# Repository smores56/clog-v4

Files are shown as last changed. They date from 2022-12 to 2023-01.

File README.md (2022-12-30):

The Clog V4
===========

The Clog V4 is a 34-key split keyboard. It has the following features:

- Choc V1 switches
- Wired or wireless with Seeeduino Xiao controllers
- Pinky clusters (top pinky keys on the sides)
- Splay (4° between middle and ring and between ring and pinky)
- Hotswap with a switch plate for stability
- SplitKB puck support for tenting

One Half of the Clog V4

## How to Order

The gerber ZIPs ((PCB)[./gerber/clog-v4.zip] and (plate)[./gerber/clog-v4-plate.zip])
have everything you'll need to get this printed. You can order from [JLC](https://jlcpcb.com)
by just uploading the ZIP archives and keeping the default options. I'd suggest removing
the order number, otherwise they'll put one on the boards somewhere randomly.

## Building

### Parts Needed

Part Name                  | Quantity        | Notes                                    | Link
--------------------------:|:---------------:|:----------------------------------------:|:----
PCB                        | 2 (halves)      |                                          | Look up
Switch Plate               | 2 (halves)      |                                          | Look up
Choc V1 Switches           | 34              |                                          | <https://mkultra.click/choc-switches>
Choc Keycaps               | 34              |                                          | <https://mkultra.click/mbk-factory-colors>
SMD Diodes                 | 34              |                                          | <https://www.aliexpress.com/item/3256802562651339.html>
Kailh Choc Hotswap Sockets | 34              |                                          | <https://mkultra.click/kailh-hotswap-sockets>
Power Switches             | 2               | optional                                 | <https://www.digikey.com/en/products/detail/nidec-copal-electronics/CUS-12TB/1124222>
Reset Switches             | 2               | optional                                 | <https://www.digikey.com/en/products/detail/e-switch/TL1014BF160QG/3910805>
Xiao (BLE)                 | 2               |                                          | <https://www.seeedstudio.com/Seeed-XIAO-BLE-nRF52840-p-5201.html>
Small LiPo Batteries       | 2               |                                          | <https://www.aliexpress.com/item/2251832610867849.html>
Inch of Copper Wire        | 1               | Use thin and sheathed                    | Any hardware store
MCU Sockets                | 1 strip to chop | Optional, chop into sections of 7 pins   | <https://www.digikey.com/en/products/detail/mill-max-manufacturing-corp/316-43-164-41-006000/1212147>
MCU Socket Pins            | 28              | Optional, buy extras, these are slippery | <https://www.digikey.com/en/products/detail/mill-max-manufacturing-corp/3320-0-00-15-00-00-03-0/4147392>

### Tips

I'd solder the parts in this order:

- Diodes
- Hotswap sockets
- Power switches
- MCU sockets/Headers that came with the Xiao's
- MCU pins if you're [socketing](https://docs.splitkb.com/hc/en-us/articles/360011263059-How-do-I-socket-a-microcontroller-)
- Batteries (To the +ve pad under the controller and to the -ve hole on the board)
- The "bodge" wire from the "Reset" hole to the reset pad under the controller

## Pictures

The Clog V4

Tented with Pucks and Manfrotto Tripods

The Clog Logo

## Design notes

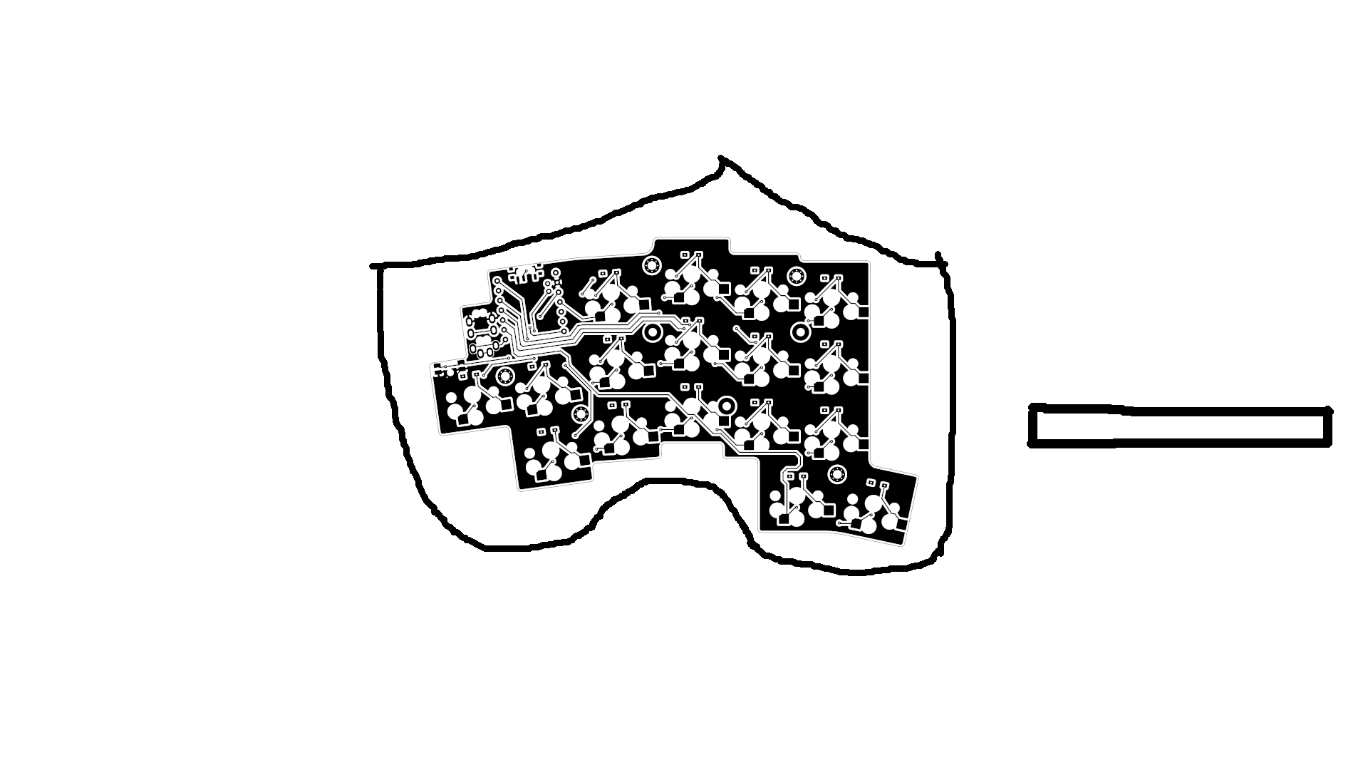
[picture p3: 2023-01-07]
art/shoe-outline-1.png

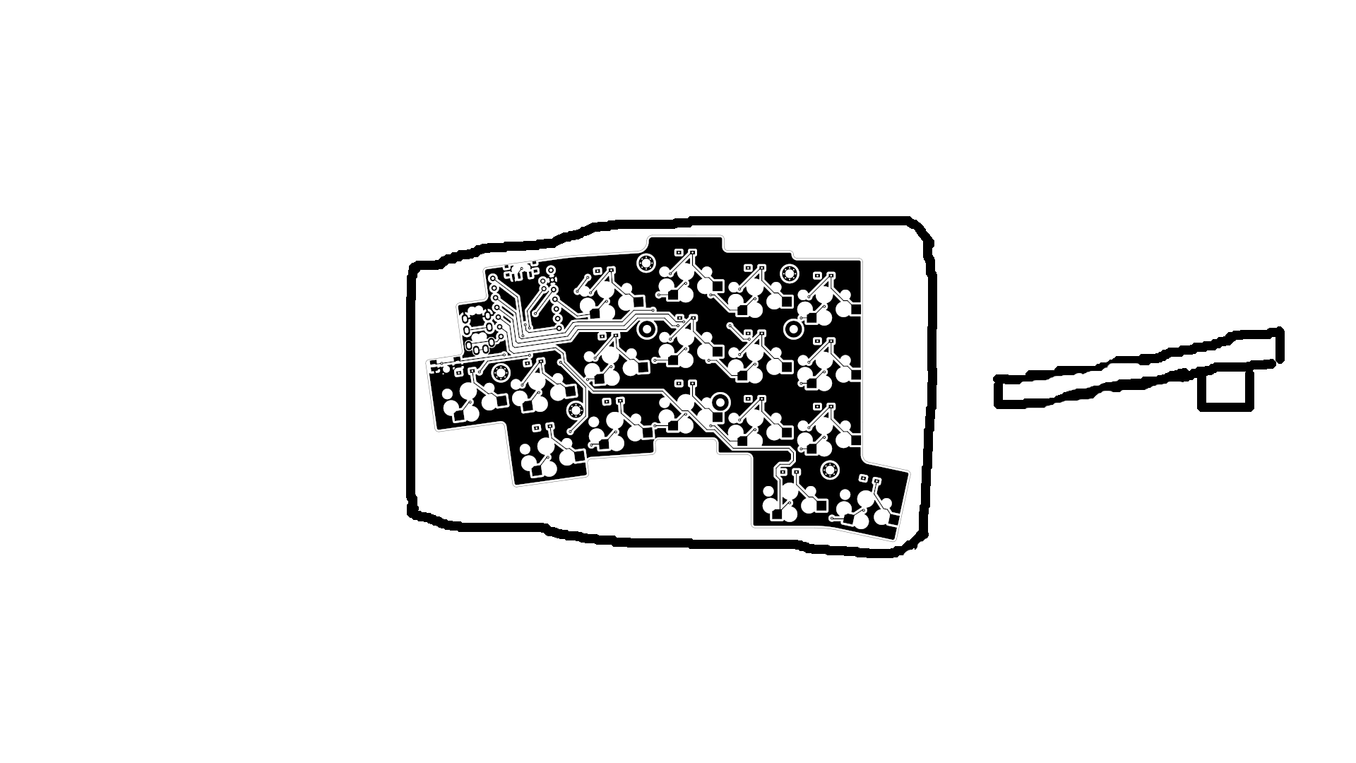
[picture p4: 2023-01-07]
art/shoe-outline-2.png

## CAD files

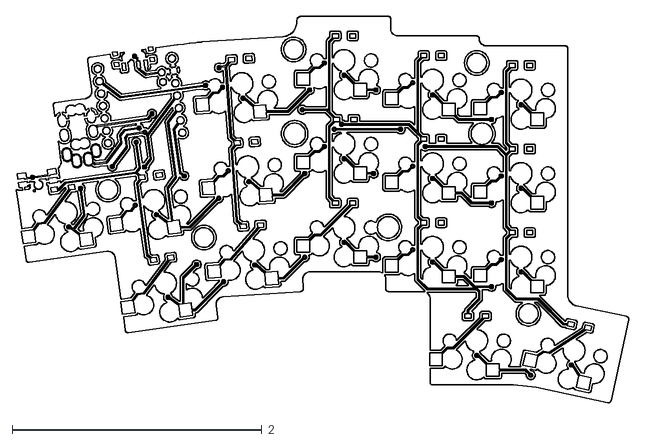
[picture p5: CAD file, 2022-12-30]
case/full-pcb.dxf
4.90 x 3.10

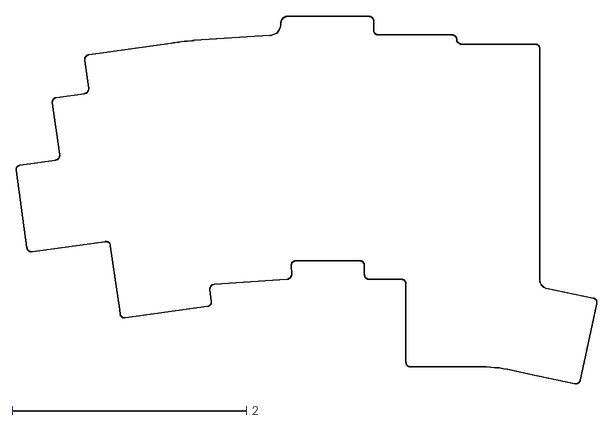
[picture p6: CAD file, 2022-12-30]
case/empty-pcb.dxf
4.96 x 3.14

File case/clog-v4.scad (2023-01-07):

hole_locations = [
    [45.9, -53],
    [26.4, -43.3],
    [64.2, -14.8],
    [101.4, -17.5],
    [111.9, -68.5],
];

pcb_thickness = 1.6;
component_thickness = 2;
case_thickness = 1.5;

plate_thickness = 1.2;
pcb_plate_gap = 1;

total_plate_thickness = plate_thickness + pcb_plate_gap;

total_thickness = pcb_thickness +
    component_thickness + case_thickness +
    total_plate_thickness;

pcb_case_margin = 0.5;
pcb_ridge_margin = 1;

case_wall_thickness = 4;

heat_insert_radius = 1.5;
strut_radius = 3;

// rendering level
$fn = 15;

right_side = true;

module pcb() {
    translate([-75, 50, 0])
    scale([25.4, 25.4, 1])
    import("empty-pcb.dxf");
}

module pcb_ghost() {
    %
    translate([0, 0, case_thickness + component_thickness])
    linear_extrude(pcb_thickness)
    pcb();
}

module pcb_cutout() {
    translate([0, 0, case_thickness + component_thickness])
    linear_extrude(pcb_thickness + total_plate_thickness + 1)
    offset(pcb_case_margin)
    pcb();
}

module component_cutout() {
    translate([0, 0, case_thickness])
    linear_extrude(component_thickness + pcb_thickness + 0.1)
    offset(-pcb_ridge_margin)
    pcb();
}

module case_body() {
    minkowski() {
        linear_extrude(total_thickness)
        offset(case_wall_thickness)
        pcb();
        sphere(0.5);
    }
}

module heat_insert_holes() {
    for (location = hole_locations) {
        translate([location[0], location[1], case_thickness + component_thickness - 3])
        linear_extrude(10)
        circle(heat_insert_radius);
    }
}

module heat_insert_struts() {
    for (location = hole_locations) {
        translate([location[0], location[1], case_thickness - 0.1])
        linear_extrude(component_thickness)
        circle(strut_radius);
    }
}

module wire_port_cutout() {
    translate([24.135, -28, case_thickness + component_thickness + total_thickness / 2+ pcb_thickness])
    rotate([0, 0, 8])
    cube([38.75, 35, total_thickness], center=true);
}

module power_switch_cutout() {
    z_rotation_base = 8;
    z_rotation_delta = 15;

    intersection() {
        translate([27.7, -18.5, 1])
        rotate([0, 0, z_rotation_base + z_rotation_delta])
        cube([12, 10, 6]);

        translate([23.7, -16, 1])
        rotate([0, 0, z_rotation_base - z_rotation_delta])
        cube([12, 10, 6]);

        translate([24.7, -17, 2])
        rotate([-10, 0, z_rotation_base])
        cube([15, 10, 6]);
    }
}

module reset_switch_cutout() {
    intersection() {
        translate([6.4, -42.3, 3])
        rotate([-15, 0, 8])
        cube([10, 15, 6]);
        
        translate([6.4, -41.03, 0])
        rotate([0, 0, 8])
        cube([10, 15, 9]);

        translate([6.4, -46, 1])
        rotate([0, 0, 28])
        cube([10, 21, 6]);
    }
}

module full_case() {
    difference() {
        union() {
            difference() {
                case_body();
                pcb_cutout();
                component_cutout();
                wire_port_cutout();
                power_switch_cutout();
                reset_switch_cutout();
            };
            heat_insert_struts();
        };
        heat_insert_holes();
        pcb_ghost();
    };
}

if (right_side) {
    translate([110, 0, 0])
    mirror([1, 0, 0])
    full_case();
} else {
    full_case();
};

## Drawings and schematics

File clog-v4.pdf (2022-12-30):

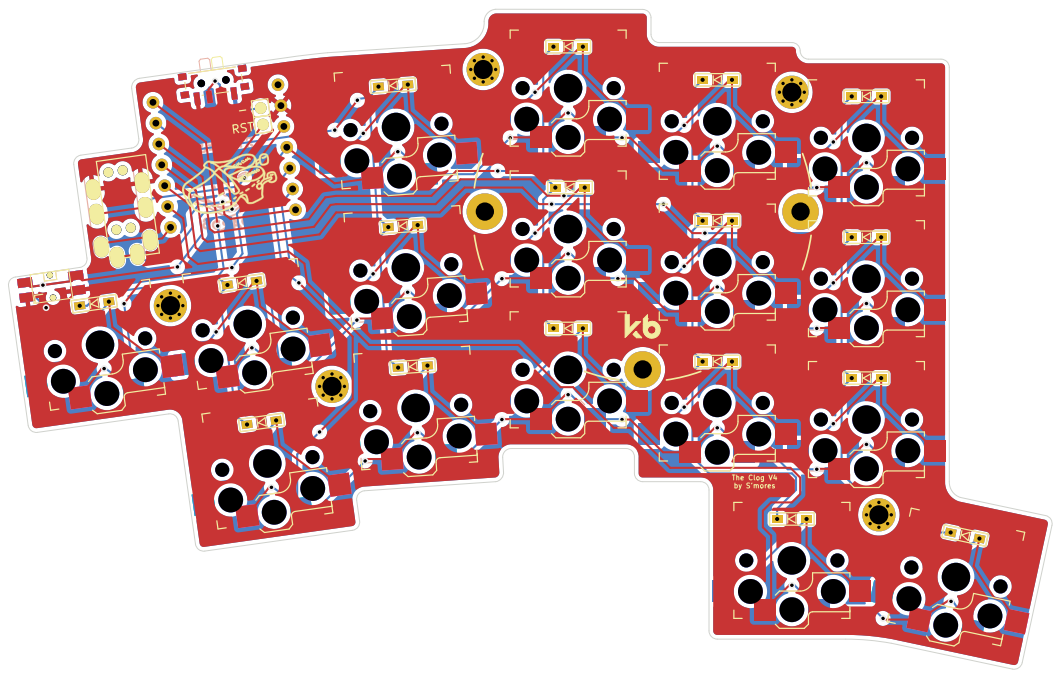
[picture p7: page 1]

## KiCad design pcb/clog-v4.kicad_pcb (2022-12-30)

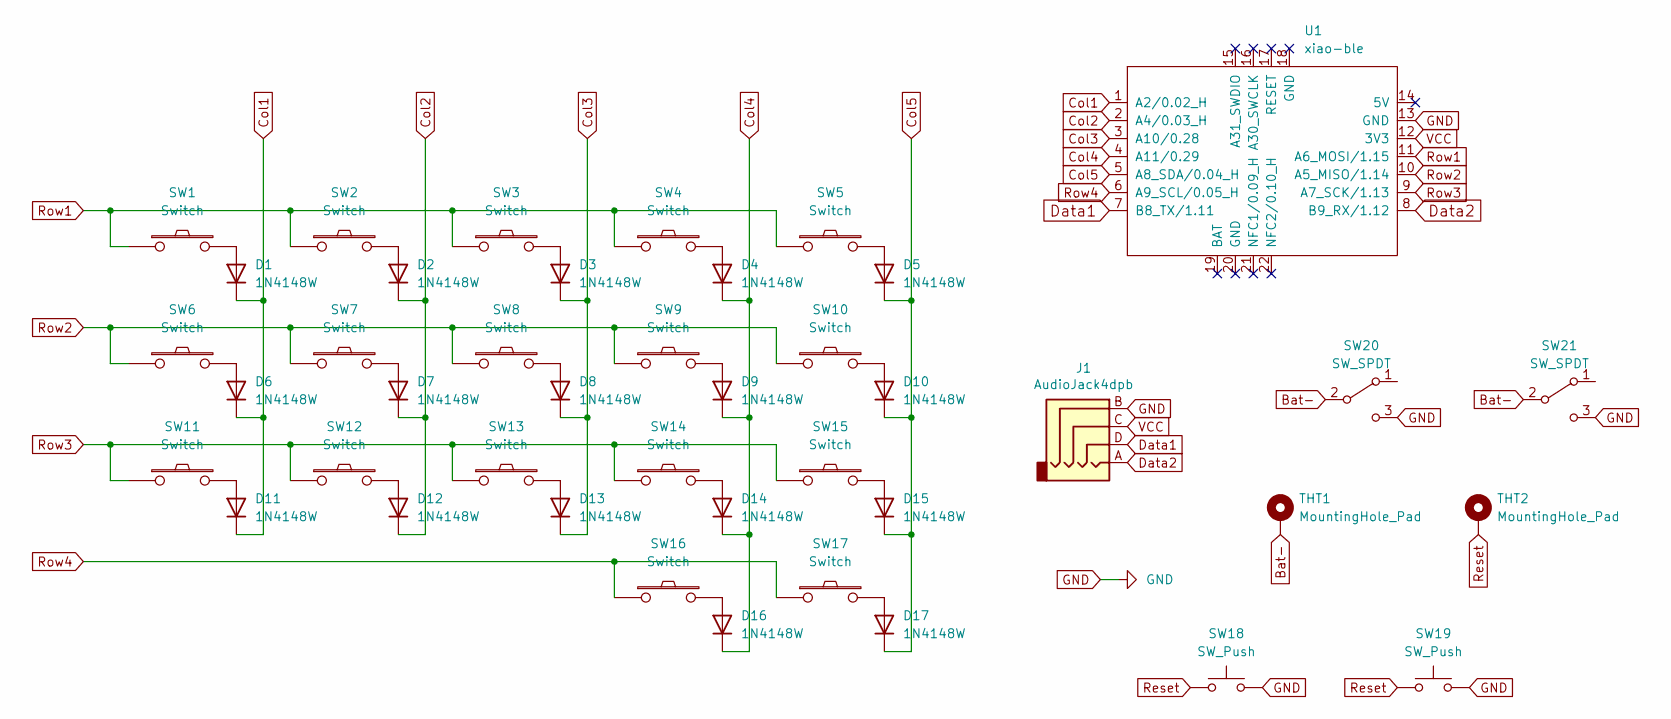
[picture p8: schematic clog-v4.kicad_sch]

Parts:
D1, D2, D3, D4, D5, D6, D7, D8, D9, D10, D11, D12, D13, D14, D15, D16, D17: 1N4148W; smd-diode
J1: AudioJack4dpb; trrs
SW1, SW2, SW3, SW4, SW5, SW6, SW7, SW8, SW9, SW10, SW11, SW12, SW13, SW14, SW15, SW16, SW17: Switch; choc-switch-socket-only
SW18, SW19: SW_Push; reset-switch-angled-4pin
SW20, SW21: SW_SPDT; power-switch
THT1, THT2: MountingHole_Pad; single-pin
U1: xiao-ble

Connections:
Bat-: SW20.2 (B), SW21.2 (B), THT1.1
Col1: D1.1 (K), D6.1 (K), D11.1 (K), U1.1 (A2/0.02_H)
Col2: D2.1 (K), D7.1 (K), D12.1 (K), U1.2 (A4/0.03_H)
Col3: D3.1 (K), D8.1 (K), D13.1 (K), U1.3 (A10/0.28)
Col4: D4.1 (K), D9.1 (K), D14.1 (K), D16.1 (K), U1.4 (A11/0.29)
Col5: D5.1 (K), D10.1 (K), D15.1 (K), D17.1 (K), U1.5 (A8_SDA/0.04_H)
Data1: J1.D, U1.7 (B8_TX/1.11)
Data2: J1.A, U1.8 (B9_RX/1.12)
GND: J1.B, SW18.2, SW19.2, SW20.3 (C), SW21.3 (C), U1.13 (GND)
unnamed: D1.2 (A), SW1.2
unnamed: D2.2 (A), SW2.2
unnamed: D3.2 (A), SW3.2
unnamed: D4.2 (A), SW4.2
unnamed: D5.2 (A), SW5.2
unnamed: D6.2 (A), SW6.2
unnamed: D7.2 (A), SW7.2
unnamed: D8.2 (A), SW8.2
unnamed: D9.2 (A), SW9.2
unnamed: D10.2 (A), SW10.2
unnamed: D11.2 (A), SW11.2
unnamed: D12.2 (A), SW12.2
unnamed: D13.2 (A), SW13.2
unnamed: D14.2 (A), SW14.2
unnamed: D15.2 (A), SW15.2
unnamed: D16.2 (A), SW16.2
unnamed: D17.2 (A), SW17.2
Reset: SW18.1, SW19.1, THT2.1
Row1: SW1.1, SW2.1, SW3.1, SW4.1, SW5.1, U1.11 (A6_MOSI/1.15)
Row2: SW6.1, SW7.1, SW8.1, SW9.1, SW10.1, U1.10 (A5_MISO/1.14)
Row3: SW11.1, SW12.1, SW13.1, SW14.1, SW15.1, U1.9 (A7_SCK/1.13)
Row4: SW16.1, SW17.1, U1.6 (A9_SCL/0.05_H)
VCC: J1.C, U1.12 (3V3)

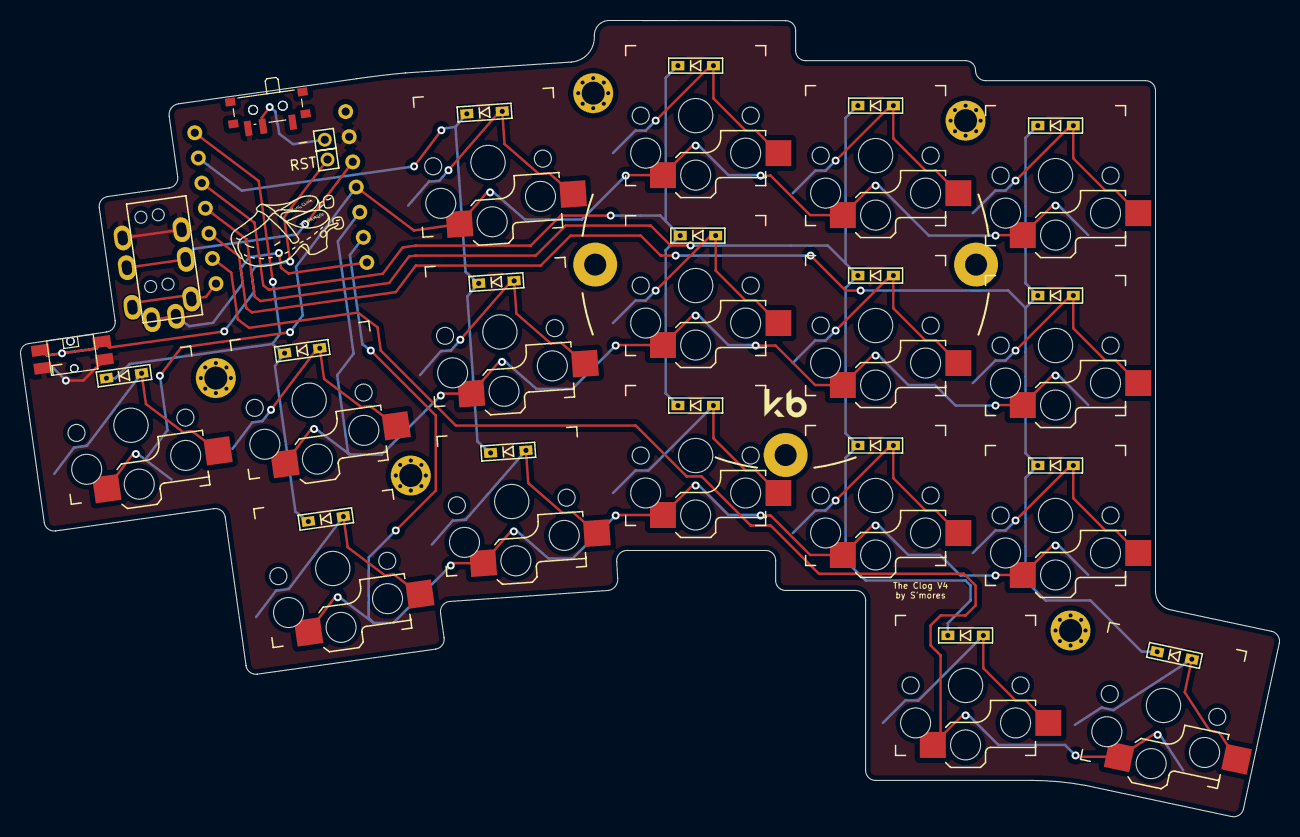
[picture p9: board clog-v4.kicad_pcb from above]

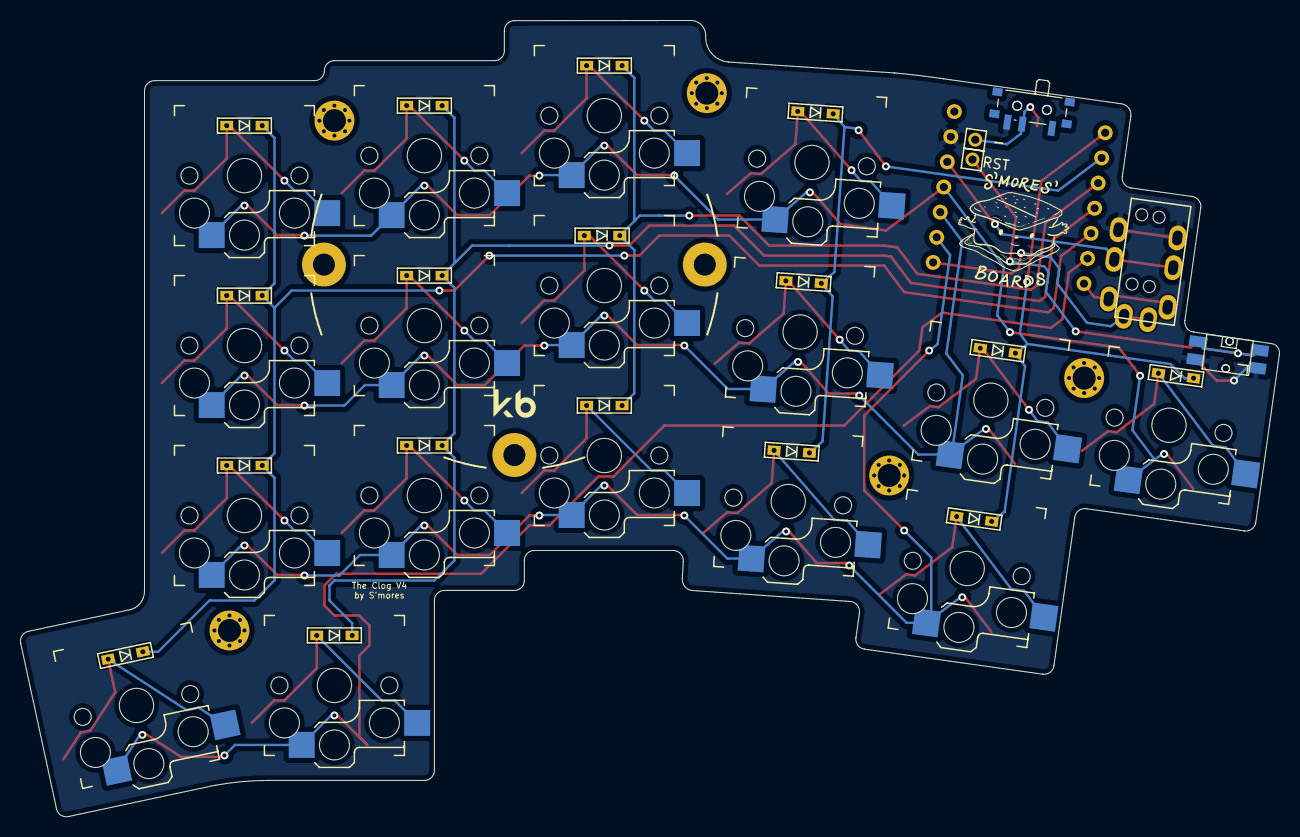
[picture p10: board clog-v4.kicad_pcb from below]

Board: 2 copper layers, 125.9 x 79.7 mm, 47 parts (2 on the bottom side), 32 nets.

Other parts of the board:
Ref**: Val**; m2-hole
Ref**#2, Ref**#3, Ref**#4, Ref**#5: Val**; m2-hole
